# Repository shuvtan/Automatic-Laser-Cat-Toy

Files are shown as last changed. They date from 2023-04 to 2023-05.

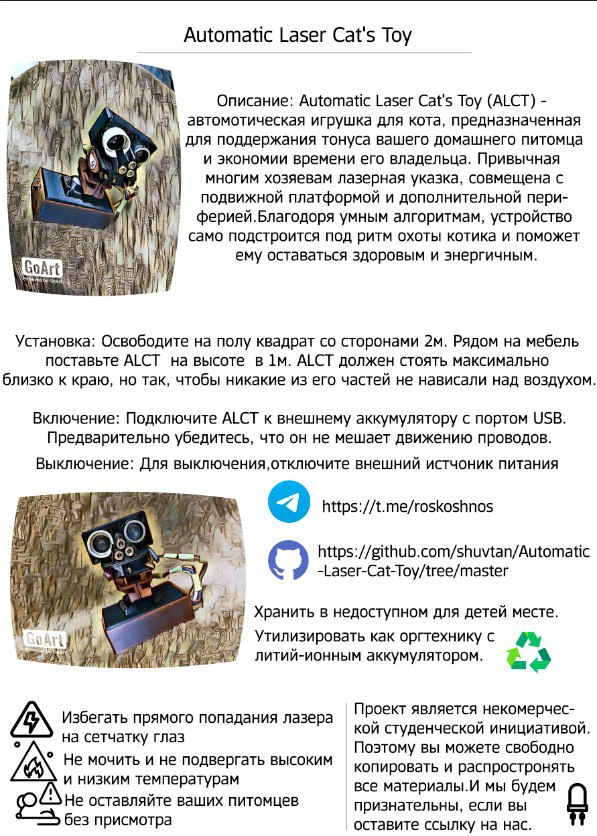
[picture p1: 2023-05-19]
ALCT_instruction.jpg

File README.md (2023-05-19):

# Automatic-Laser-Cat-Toy

**НПО Роскошнос представляет...**

*Автоматическая лазер-игрушка для котиков*

# Структура
Идея продукта: [ALCT idea](https://github.com/shuvtan/Automatic-Laser-Cat-Toy/blob/master/ALCT%20idea.pdf)

Документация продукта и протокол испытаний: [ALCT_production](https://github.com/shuvtan/Automatic-Laser-Cat-Toy/blob/master/ALCT%20%D0%94%D0%BE%D0%BA%D1%83%D0%BC%D0%B5%D0%BD%D1%82%D0%B0%D1%86%D0%B8%D1%8F%20%D0%B8%20%D0%BF%D1%8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)

Инструкция пользователя: [ALCT_instruction](https://github.com/shuvtan/Automatic-Laser-Cat-Toy/blob/master/ALCT_instruction.jpg)

Схема систем: [ALCT Cхема систем](https://github.com/shuvtan/Automatic-Laser-Cat-Toy/blob/master/ALCT%20%D0%A1%D1%85%D0%B5%D0%BC%D0%B0%20%D1%81%D0%B8%D1%81%D1%82%D0%B5%D0%BC.jpg)

Прошивка устройства и тест-код: [Код](https://github.com/shuvtan/Automatic-Laser-Cat-Toy/tree/master/%D0%9A%D0%BE%D0%B4) -

Модели для 3D печати: [Модели 3D печать](https://github.com/shuvtan/Automatic-Laser-Cat-Toy/tree/master/%D0%9C%D0%BE%D0%B4%D0%B5%D0%BB%D0%B8%203D%20%D0%BF%D0%B5%D1%87%D0%B0%D1%82%D1%8C)

# Соцсети
За процессом работы следите в нашем Telegram канале: [РОСКОШНОС](https://t.me/roskoshnos)

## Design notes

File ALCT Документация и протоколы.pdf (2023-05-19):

ФЕДЕРАЛЬНОЕ ГОСУДАРСТВЕННОЕ АВТОНОМНОЕ ОБРАЗОВАТЕЛЬНОЕ УЧРЕЖДЕНИЕ ВЫСШЕГО ОБРАЗОВАНИЯ МОСКОВСКИЙ ФИЗИКО-ТЕХНИЧЕСКИЙ ИНСТИТУТ (НАЦИОНАЛЬНЫЙ ИССЛЕДОВАТЕЛЬСКИЙ УНИВЕРСИТЕТ) ФАКУЛЬТЕТ ОБЩЕЙ И ПРИКЛАДНОЙ ФИЗИКИ

Документация инженерного продукта Автоматическая лазерная игрушка для котов Automatic Laser Cat’s Toy

Мясникова Алина, Стельмух Никита, Сметанина Елена, Шувайникова Татьяна

Долгопрудный, 2023 г.

## 1 Описание

Автоматическая лазерная игрушка для кота - далее устройство.

Данное устройство представляет собой совокупность систем модулей электроники, управление которыми производится с помощью микроконтроллера Arduino Nano.

Применение: При подключении устройства в сеть, фиксируется игровая площадка, после чего загораются три лазера, способные привлечь внимание кота. В режиме реального времени с помощью дальнометра устройство способно определить поймал кот лазер или нет. В зависимости от этого с помощью сервоприводов лазеры направляются в другую точку, изменяя направление цели кота.
Таким образом устройство поможет отвлечь кота, пока хозяин занят своими делами.

## 2 Комплектация

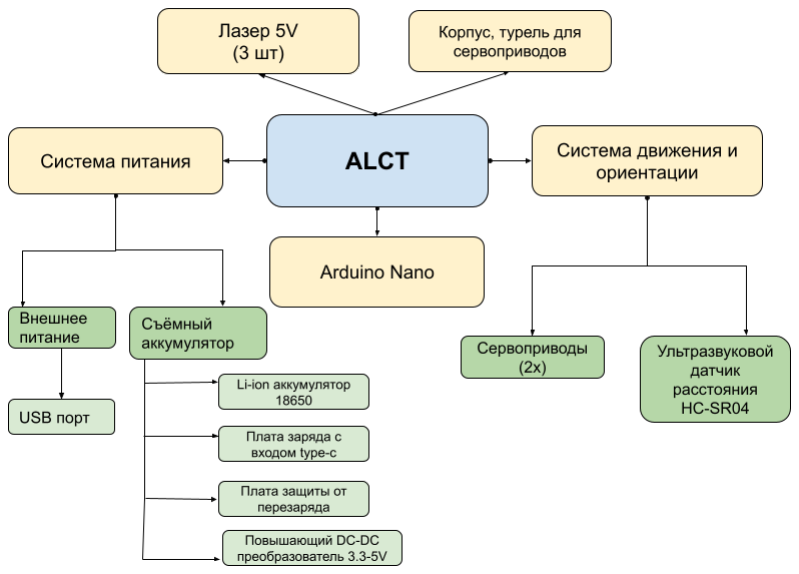
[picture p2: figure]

Рис. 1: Схема деления систем устройства

Устройство состоит из 5 основных систем:

1. Бортовая машина
- Микроконтроллер Arduino Nano
- Тактовая кнопка для перезагрузки платы
2. Полезная нагрузка
- Лазер 5V (3 шт.)

3. Корпус
- Основной корпус для электронники
- Крышка корпуса
- Турель для сервоприводов SG90/MG90
- Корпус для датчика дальности
- Держатель лазеров
4. Система питания

4.1 Внешнее питание

- USB порт

4.2 Съёмный аккумулятор

- Li-ion аккумулятор 18650
- Плата заряда с входом type-c
- Плата защиты от перезаряда (может идти вместе с аккумулятором)
- Повышающий DC-DC преобразователь 3.3-5V
- Микропереключатель
- Светодиоды для определения состояния
5. Система движения и ориентации
- Сервопривод SG90
- Сервопривод MG90
- Ультразвуковой датчик дальности HC-SR04

После составления сметы, была посчитана примерная стоимость продукта - 2480 рублей.
Данная стоимость была расчитана на основании стоимости электронных компонент в интернет магазине chip.dip. (https://www.chipdip.ru/)

Стоит отметить, что 3D печать элементов корпуса обошлась бесплатно. Приносим благодарность Физтех.Фабрике (https://miptfab.ru/) !

Компоненты | шт | Цена, руб
Плата Arduino Nano | 1 | 300
Сервомотор SG90 | 1 | 150
Сервопривод MG90 | 1 | 200
Ультразвуковой датчик HC–SR04 | 1 | 450
Лазер 5V | 3 | 100
Резистор 133 Ω | 1 | 100
Аккумулятор Li-ion 18650 с защитой | 1 | 930
Плата с гнездом USB Type-C | 1 | 150
Повышающий DC-DC преобразователь до 5 В | 1 | 60
Тактовая кнопка | 1 | 15
Микропереключатель | 1 | 25
Корпус | 1 | 0
Крышка для корпуса | 1 | 0
Турель для сервоприводов SG90/MG90 | 1 | 0
Итого: | | 2480

Таблица 1: Стоимость компонент

## 3 Технические характеристики

1. Микроконтроллер Arduino Nano
В качестве бортовой машины используется микроконтроллер Arduino Nano. Такой выбор был сделан из-за компактности при достаточной эффективности. Данная машина работает на чипе ATmega328P.

Технические характеристики:

- Напряжение питания 5В;
- Количество цифровых пинов – 14, из них 6 могут использоваться в качестве выходов ШИМ;
- 8 аналоговых входов;
- Максимальный ток цифрового выхода 40 мА;
- Флэш- память 16 Кб
- ОЗУ 1 Кб
- Частота 16 МГц;
- Размеры 19 х 42 мм;
- Вес 7 г.
2. Дальнометр HC-SR04
Принцип работы: Ультразвуковой датчик расстояния работает по принципу эхолокации — посылает пучок ультразвука и получает его отражение с некоторой задержкой, с помощью которой рассчитывается расстояние до объекта.

На передней части модуля расположено два ультразвуковых датчика, первый с надписью T (Transmiter) является передатчиком ультразвуковых волн, а второй с надписью R (Receiver) служит приёмником отражённых волн.

Подключение: Датчик оснащён четырьмя выводами. Два стандартных вывода для питания и земли, вывод Trig подключается к цифровому пину Arduino в качестве сигнала входа, вывод Echo подключается к цифровому выводу Arduino в качестве сигнала вывода.

Этапы получения данных с помощью датчика:

- На выход Trig подаётся импульс длительностью 10 микросекунд;
- Трансмиттер отправляет 8 импульсов с частотой 40 кГц;
- Когда импульсы отразятся от препятствия и будут приняты ресивером, то на выходе Echo образуется входной сигнал;
- Ширина импульса преобразуется в расстояние с помощью формулы.Чтобы получить расстояние в сантиметрах, нам необходимо разделить ширину импульса на 58.

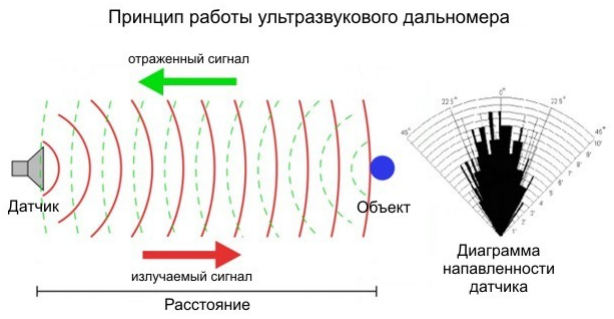
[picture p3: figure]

Рис. 2: Принцип работы дальнометра

Технические характеристики:

- Напряжение питания: 5В
- Диапазон расстояний: 2–400 см
- Точность: 0.3 см
- Эффективный угол обзора: 15°
- Рабочий угол наблюдения: 30°
- Рабочая температура: от 0°С до +60°С
- Габариты: 45мм×20мм×15мм

3. Сервоприводы SG90 и MG90

Сервопровид типа SG90 расположен в нижней части конструкции устройства. Данный датчик отвечает за поворот устройства в горизонтальной плоскости (XoY).

Характеристики SG90:

- Скорость вращения (4.8В без нагрузки): 0.14 сек/60 градусов
- Максимальный угол поворота: 180 градусов
- Рабочая температура: от -30°С до +60°С
- Рабочее напряжение: 3.5 - 8.4В
- Габариты: 22.6 x 21.8 x 11.4 мм
- Масса: 13 г.

Сервомотор типа MG90 расположен в верхней части устройства. Данный датчик отвечает за поворот устройства в вертикальной плоскости (XoZ).

Характеристики MG90:

- Скорость вращения (4.8В без нагрузки): 0.1 сек/60 градусов
- Максимальный угол поворота: 160 градусов
- Рабочая температура: от -30°С до +60°С
- Рабочее напряжение: от 3V до 7.2V (Вольт)
- Габариты: 22mm x 11.5mm x 22.5mm
- Масса: 9 г.
4. Лазерный излучатель 5В

Лазерный излучатель с радиатором охлаждения - это простой и недорогой вариант точечного света.

Характеристики:

- Напряжение питания: 5 Вольт DC
- Цвет излучения: 650 нм (красный)
- Вид излучения: точка
- Рабочий ток: < 40 мА
- Мощность излучения: < 5 мВт
- Размеры: диаметр 6 мм, длина 10.5 мм
- Рабочая температура: от -36℃ до 65℃

## 4 Алгоритмизация

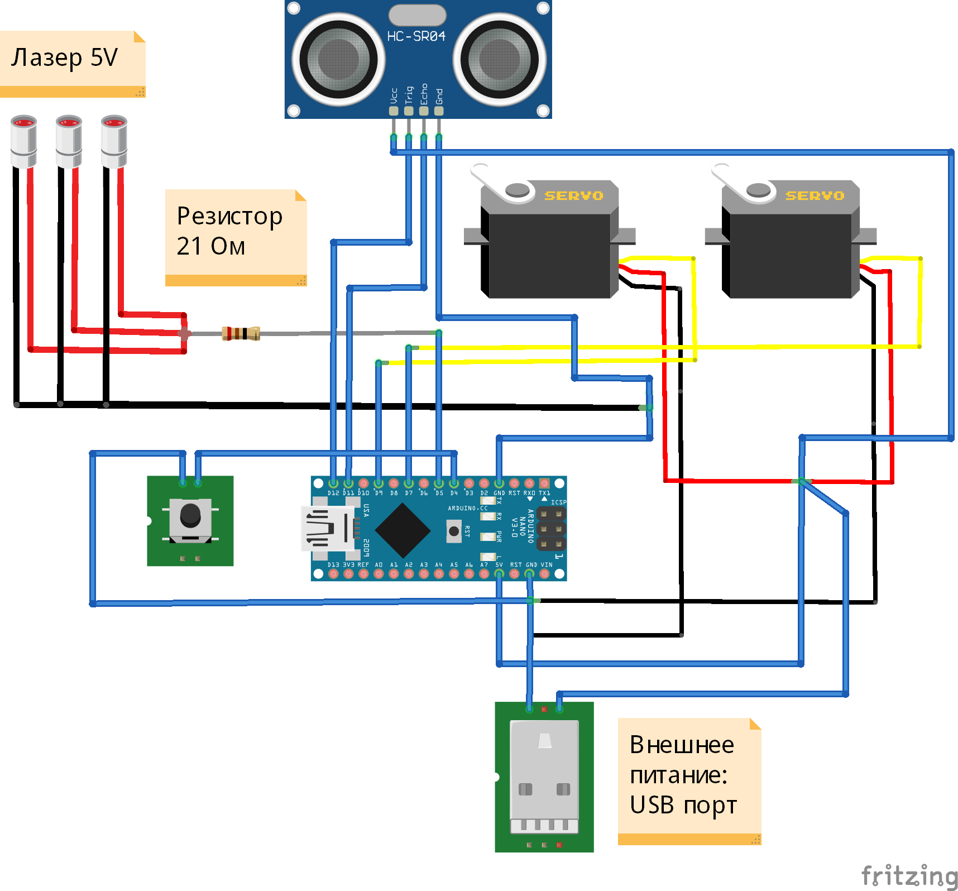
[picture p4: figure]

Рис. 3: Схема соединения модулей электронники

Компонента | PIN
Сервомотор SG90 | 7
Сервопривод MG90 | 9
Датчик дальности - TRIG | 12
Датчик дальности - ECHO | 11
Лазеры 5V | 5
Тактовая кнопка | 4

Таблица 2: Распиновка электронники

В прошивке устройства использованы базовые программы работы движения сервоприводов на рандомный угол и фиксации изменения расстояния до объекта с помощью дальнометра.

Логика кода: Если расстояние, зафиксированное датчиком изменилось более, чем на 10 см, то кот поймал лазер -> через секунду лазер поменяет положение с помощью движения сервоприводов. Если в течение минуты изменение расстояния не было зафиксировано (кот по какой-либо причине не поймал лазер), то вновь срабатывает алгоритм поворота - лазер перебегает в другое место. Код с подробными комментариями смотрите в репозитории гитхаб в папке Код (https://github.com/shuvtan/Automatic-Laser-Cat-Toy/tree/master/%D0%9A%D0%BE%D0%B4)

## 5 Корпус

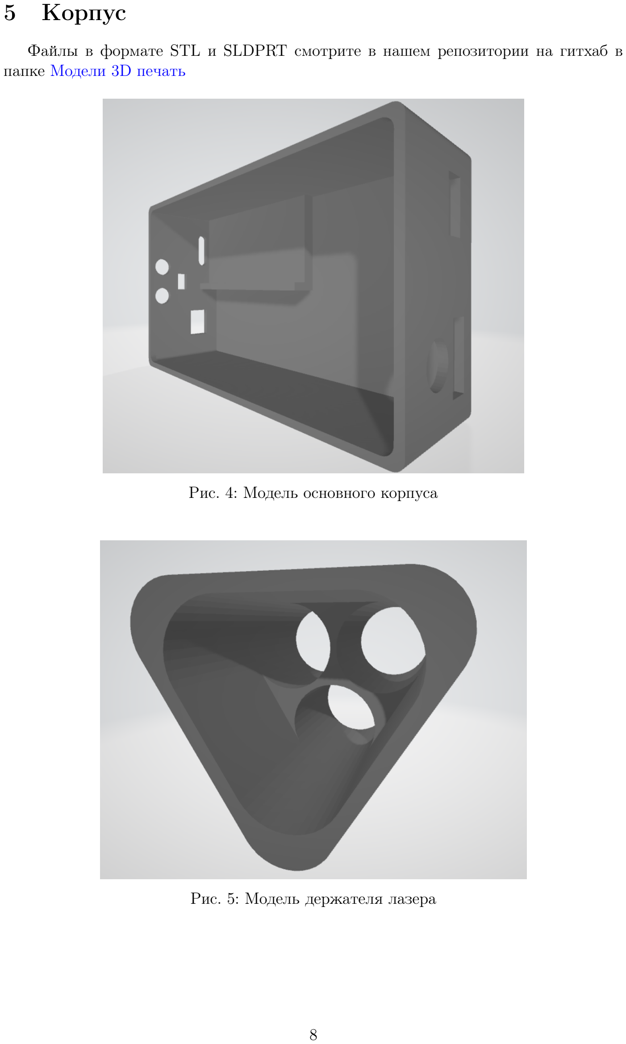
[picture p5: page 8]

Файлы в формате STL и SLDPRT смотрите в нашем репозитории на гитхаб в папке Модели 3D печать (https://github.com/shuvtan/Automatic-Laser-Cat-Toy/tree/master/%D0%9C%D0%BE%D0%B4%D0%B5%D0%BB%D0%B8%203D%20%D0%BF%D0%B5%D1%87%D0%B0%D1%82%D1%8C)

Рис. 4: Модель основного корпуса

Рис. 5: Модель держателя лазера

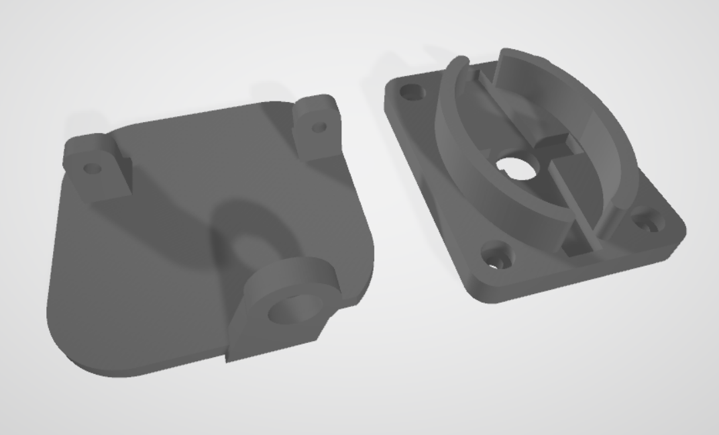
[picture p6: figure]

Рис. 6: Модель нижней и верхней частей турели для сервоприводов

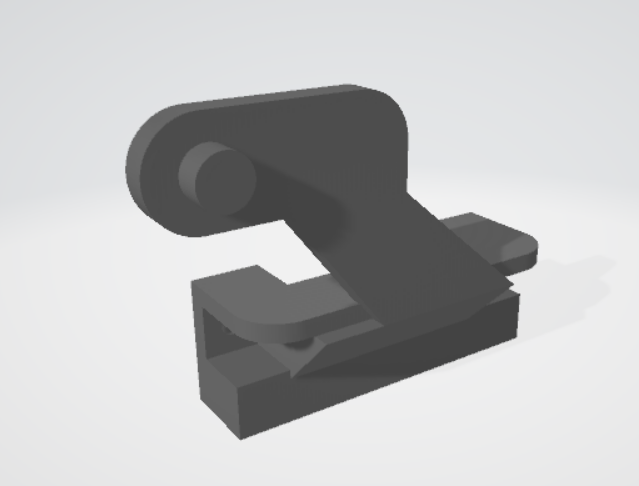
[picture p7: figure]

Рис. 7: Модель боковой части турели для сервоприводов

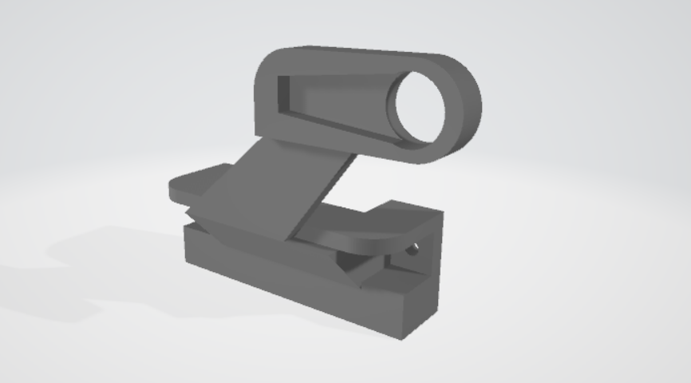
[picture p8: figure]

Рис. 8: Модель боковой части турели для сервоприводов

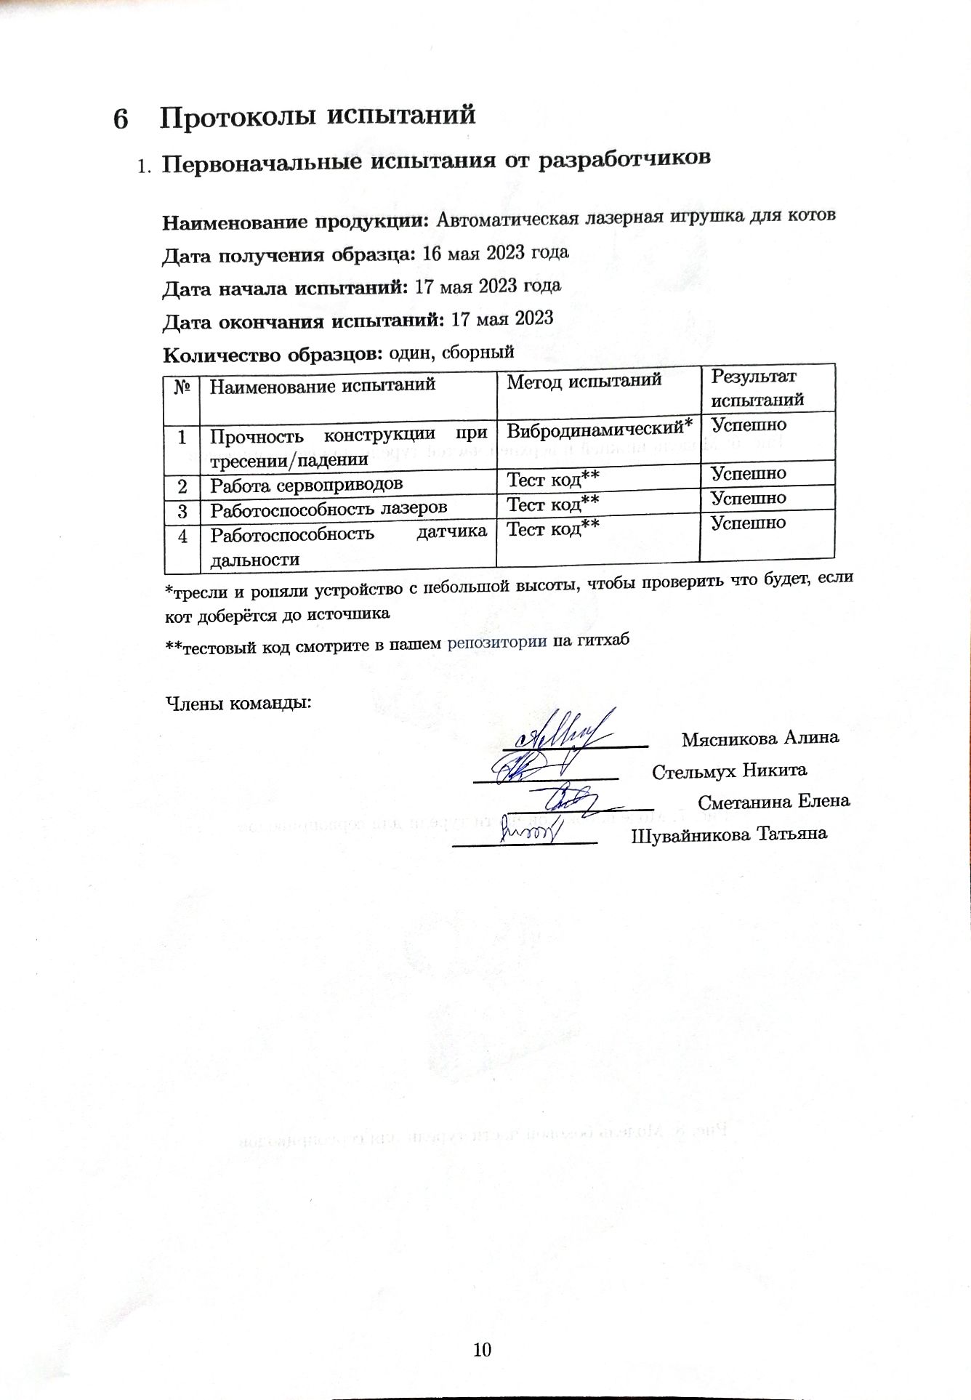
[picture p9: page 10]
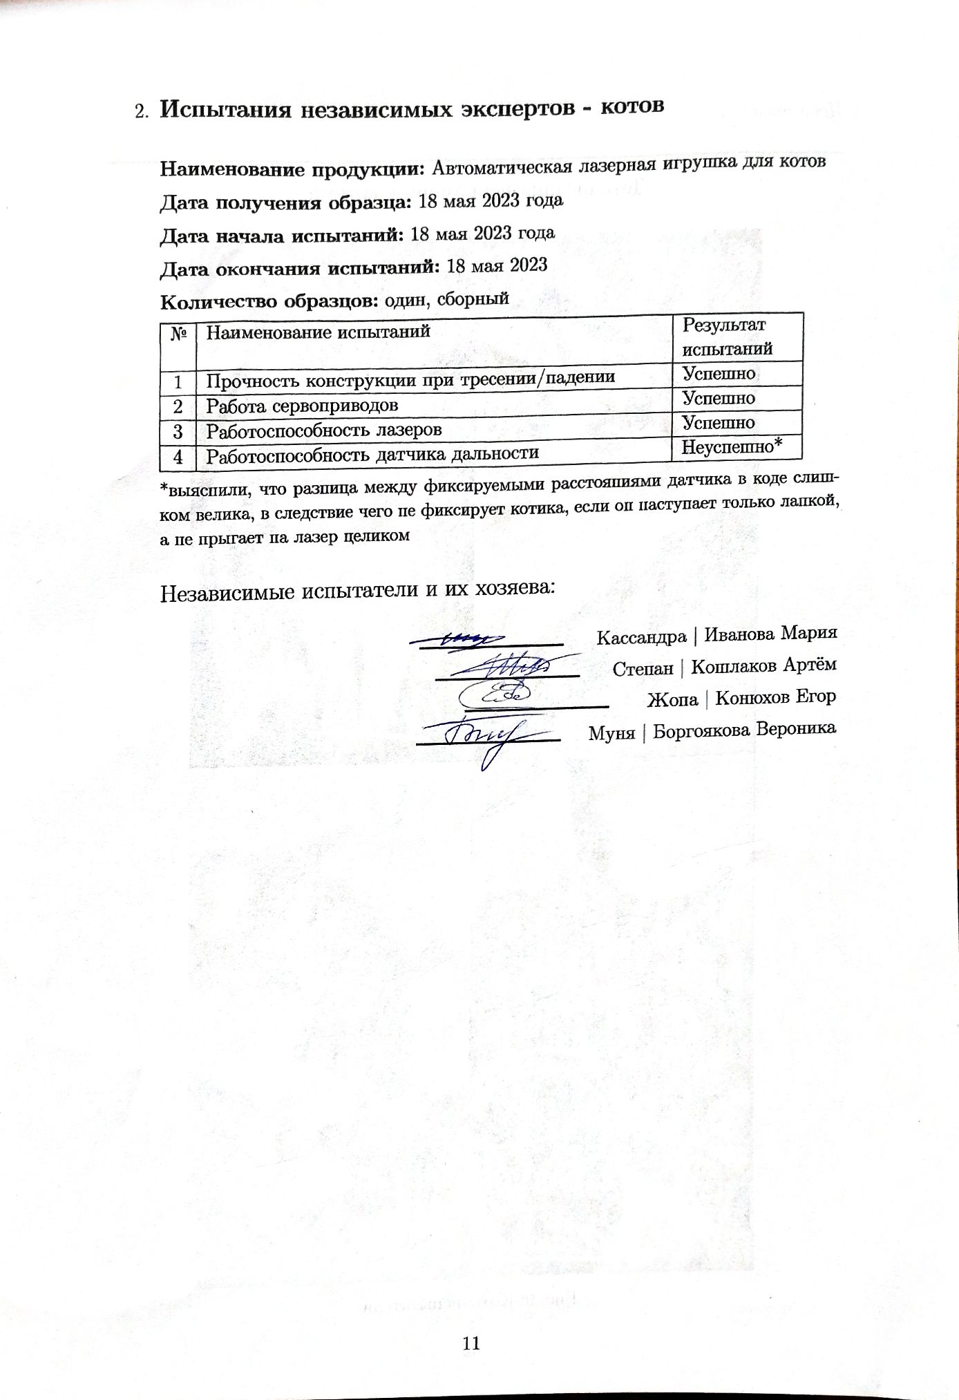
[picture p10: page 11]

Приложение 1

Детализация испытаний с котами

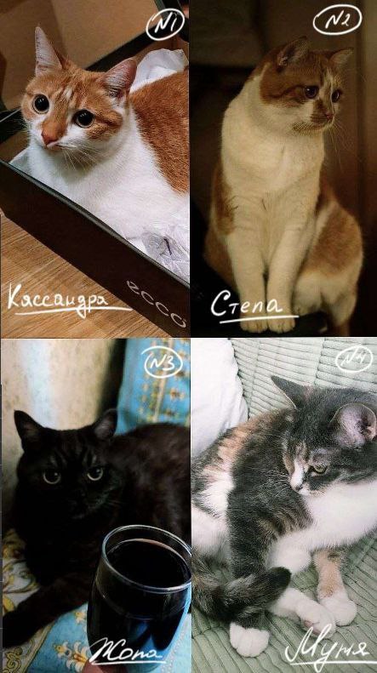
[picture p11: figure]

Рис. 9: Коты-испытатели

1. Кассандра

Кассандра несильно заинтересовалась лазерной игрушкой. Мы думаем, что это может быть связано с ярким освещением комнаты, в которой проводились испытания. Чтобы не подвергать котиков опасности попадания лазера в глаза, лазер настроен не на полную мощность, из-за чего в слишком хорошо освещённой комнате кот может не заметить игрушку.
Кассандра оказалась умной кошечкой. Услышав звук, она заинтересовалась непосредственно источником, её привлекло именно вращение самого устройства, а не лазерный луч, излучённый им. Вскоре кошка потеряла интерес к устройству вообще.

В ходе первого эксперимента мы сталкнулись с двумя проблемами:

- Звук, издаваемый сервоприводами при повороте привлёк кошку больше, чем сам лазер.
- Лазер плохо видно в освещённой комнате
2. Степан

Степан оказался более заинтересованным в происходящем. Вначале игрушку расположили слишком низко - на стуле. Поэтому Степа заинтересовался источником, тщательно его изучил, даже потрогал. Так мы убедились в том, что если кот доберётся до игрушки, то вряд ли будет атаковать, скорее заинтересуется или даже немного испугается при очередном движении сервоприводов. После этого лазерную игрушку переместили повыше - на стол. К сожалению, Степан тоже больше был заинтересован в звуках, чем в лазерном луче. К тому же он порой отвлекался на какие-либо другие посторонние звуки, например работающая в комнате мультиварка.
Тем неменее спустя время, аккуратный Степан осмелился потрогать луч, располагающийся у него прямо под лапками. После чего немного походил за лазером, но быстро устал и ушёл спать на своё место.

В момент, когда Степа тронул лапой лазерную точку мы увидили главную на данный момент проблему - неисправность режима датчика дальности! После того, как кот тронул точку, она не сдвинулась, потому что изменение расстояния было меньше 10 см (лапка кота поменьше).

В ходе второго эксперимента мы сталкнулись с двумя новыми проблемами:

- Постаронние звуки отвлекали кота от лазерной игрушки
- Слишком осторожный кот будет ловить лазер лапкой, которая даст результат изменения расстояния меньше 10 см, предполагаемого в прошивке устройства.

3. Жопа

Жопа оказался достаточно пугливым котом, поэтому испытания проводили только сами хозяева, поделившись с нами видеоматериалами.
В отличие от первых двух экспериментов данное испытание проводилось в более тёмном помещении. К сожалению это не повлияло на повышение интереса кота к игрушке.

Жопа внимательно наблюдал за лазерной точкой, но не атаковал её. Тут мы увидели ещё одну недоработку. В данном эксперименте лазер часто попадал на самого кота сзади например, так, что кот не понимал где находится лазер, не видел его, из-за чего мог потерять интерес.

Снова была подтверждена проблема срабатывания алгоритма по изменению расстояния датчика дальности, т.к. Жопа если ловил лазер, то только лапой, не слишком активно, в следствие чего расстояние менялось менее чем на 10 см.

В ходе третьего эксперимента мы сталкнулись с новыми проблемой:

- Режим работы лазера не исключает случая, когда лазер попадает на тело кота таким образом, что кот теряет лазер, не понимая, что происходит
4. Муня

Самым активным и заинтересованным испытателем определённо стала Муня. У этой кошечки хорошо развиты охотничьи инстинкты, ей понравилось охотиться за лазером. Она активно прыгала и нападала на лазерную точку, иногда отходя в засаду, чтобы выждать подходящего момента.

Так мы проверили срабатывание движения сервоприводов по таймеру, если кот не ловит лазерную точку более минуты. Снова убедились в недееспособности алгоритма измерения изменения расстояния, при случаях, если Муня ловила лазер только лапкой. Но к счастью это не помешало данной кошечке насладиться игрой, потому что она активно атаковала лазерный луч, в следствие чего измеренная разница расстояний была определенно больше 10 см.

Стоит отметить новую проблему для активных котиков: после выключения лазера кошечка продолжнала искать его по всей комнате. Кроме того охотница слишком разыгралась и перевозбудилась, потому что играла около 12 минут.

В ходе последнего эксперимента мы сталкнулись с новой проблемой:

- Активные котики могут слишком сильно разыграться, если использовать игрушку долго - более 10 минут.

## 7 Итоги испытаний и дальнейшая разработка

Основные проблемы и анализ их решения:

- В ходе испытаний стало понятно, что разницу изменения расстояния, в момент, когда кот поймает лазер нужно делать менее 10 см, как мы поставили изначально. Тем не менее меньше 5 см делать ёё тоже не стоит, т.к. из-за неточности измерения значений датчика будут ловиться бесконечные ложные срабатывания, такие, что точка ни на мг не застынет на месте.
Было принято решение поменять данный параметр на 8 см.
- Кроме того в ходе испытаний было проверено, что остальные проблемы возникшие при проектировке устройства были решены качественно, так, что системы работают исправно.
- Трения между сервоприводами и колебаний устройства за счёт смещения центра масс не наблюдалось. Значит подкладки справляются достаточно хорошо, проблема, возникшая во время проектировки решена качественно.
- Чтобы сузить радиус углового обзора датчика дальности и сфокусировать датчик дальности на измерение расстояния непосредственно до объекта точечно, куда падает лазер, был спроектирован небольшой цилиндр, сужающий угол обзора датчика.
Вначале испытаний мы заподозрили, что алгоритм изменения координат не срабатывает именно из-за перекрытия цилиндром сигнала датчика, но сняв данную деталь мы убедились, что это не так. Несрабатывания алгоритма происходят именно из-за просчётов в измерении разницы расстояний, а не из-за перекрытия сигнала.
Наличие цилиндра показало, что с ним реакция датчика на посторонние движения вне точки лазера всё же уменьшеается, т.е. данное инженерное решение было результативным и верным.

Идеи дальнейшего развития продукта:

- Добавление новых алгоритмов, расчитанные на котиков разной активности
- Питание от съёмного аккумулятора 3.3V
- Выбор режима пользователем (например яркости лазера, режимом игры по активности кота и т.п.)

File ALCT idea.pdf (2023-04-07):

# Automatic Laser Cat’s Toy

## “НПО Роскошнос” представляет…

Московск Фко-технческ нсттут , 2023

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

## Научно-технческе адач:

◇ Собрать модель автоматческо лаерно укак, меняюще свое направлене в авсмост от поведеня кота, на основе Arduino Nano
◇ Раработать несколько алгортмов-паттернов для котов рано актвност
◇ Испытать прбор, проаналровать поведене котовтестровщков

## Схема сстем:

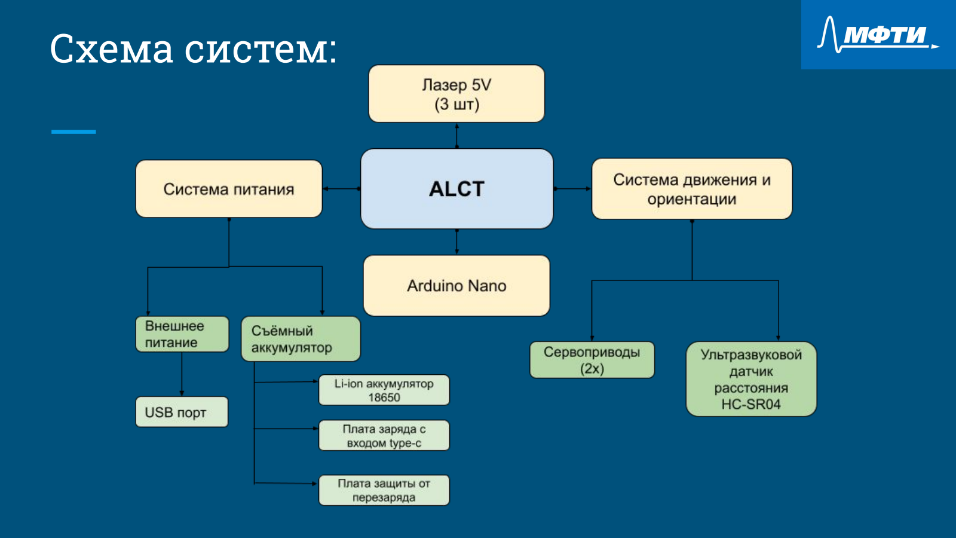
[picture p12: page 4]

## Состав команды:

- Стельмух Нкта - руководтель НПО, ненер-электронщк
- Мяснкова Ална - конструктор, smm-менедер
- Сметанна Елена - конструктор, сследователь
- Шуванкова Татьяна - программст алгортмов, сследователь

МФТИ, Факультет аэрокосмческх технолог, группа: Б03-102

## План-графк работы:

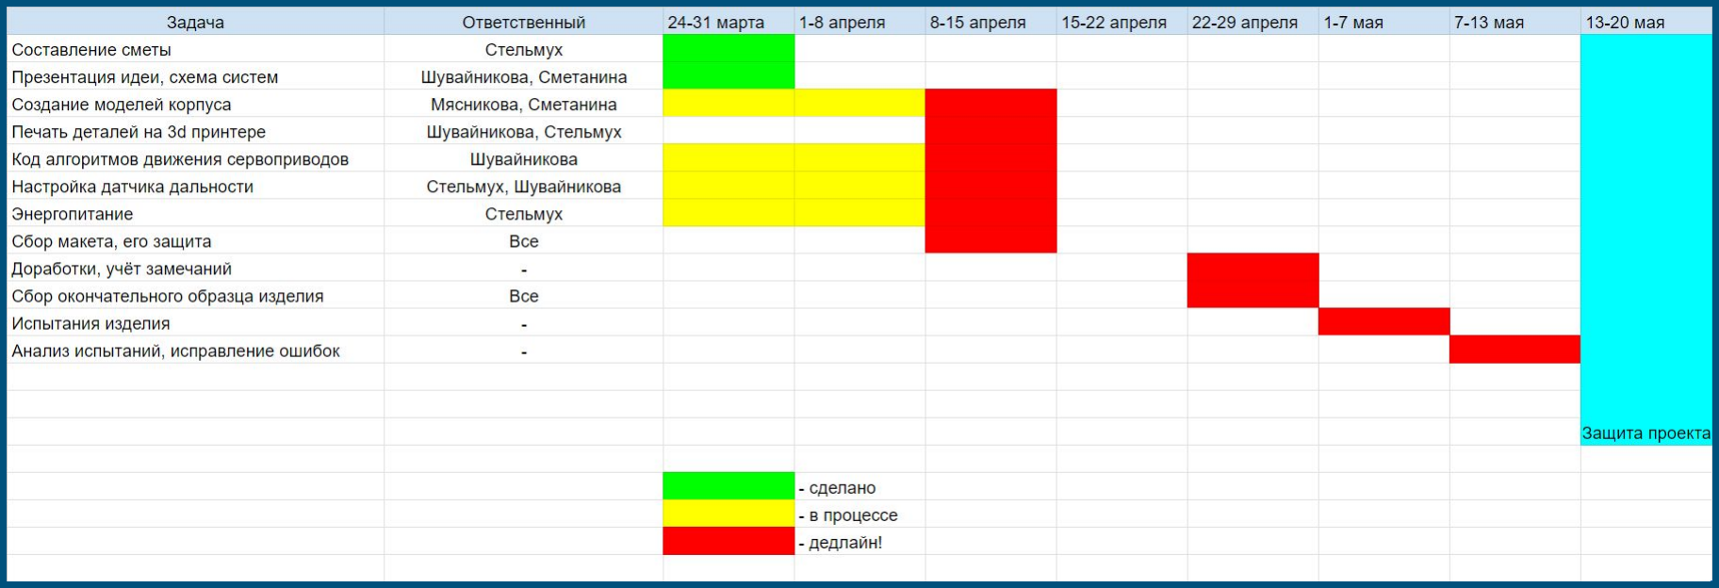
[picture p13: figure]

## Следте а нашм прогрессом…

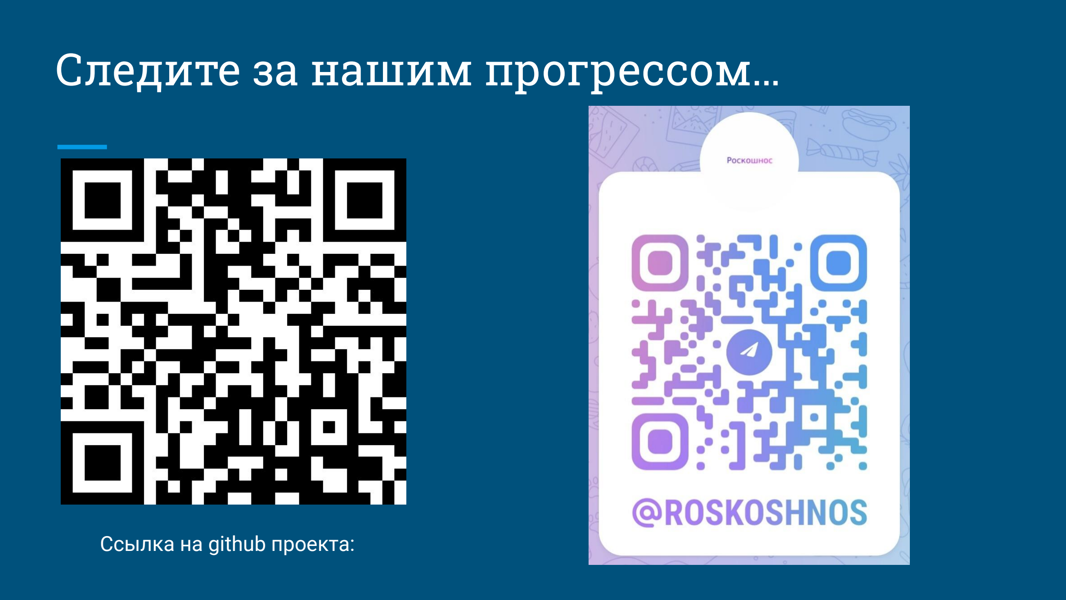
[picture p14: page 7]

Ссылка на github проекта:
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

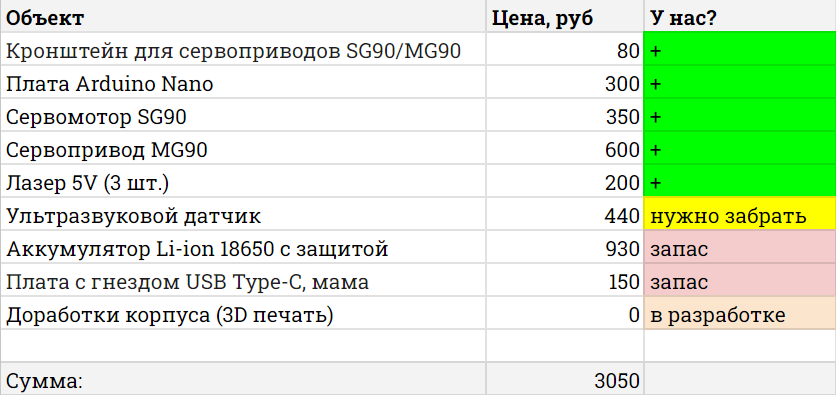
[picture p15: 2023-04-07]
ALCT Смета.png

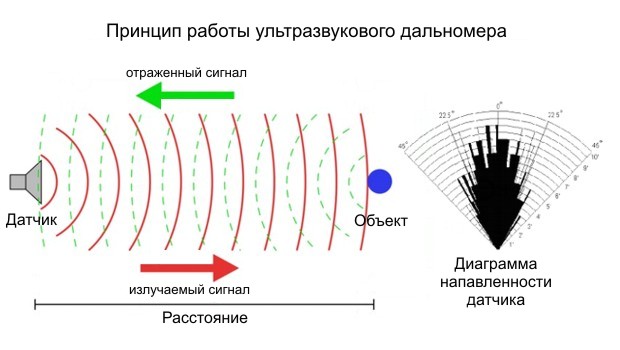
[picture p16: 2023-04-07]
Принцип работы ультразвукового датчика.jpg

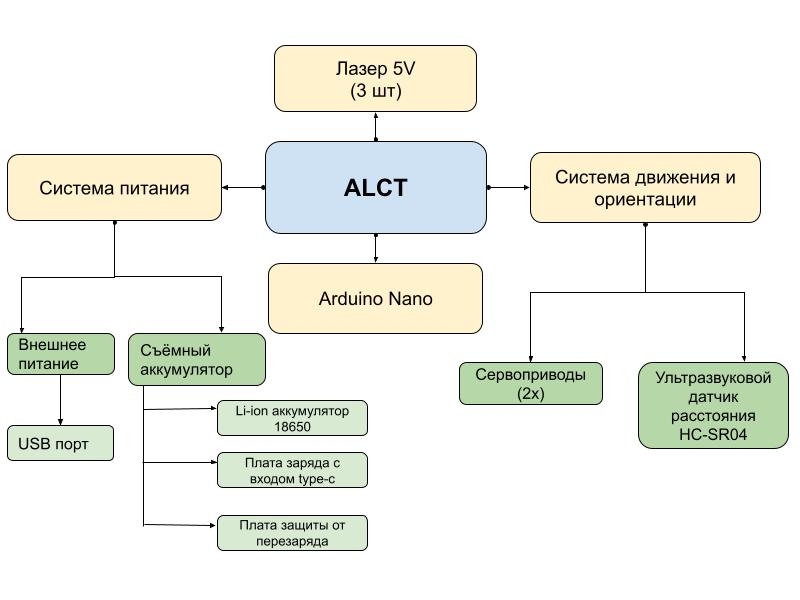
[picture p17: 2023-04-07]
ALCT Схема систем.jpg

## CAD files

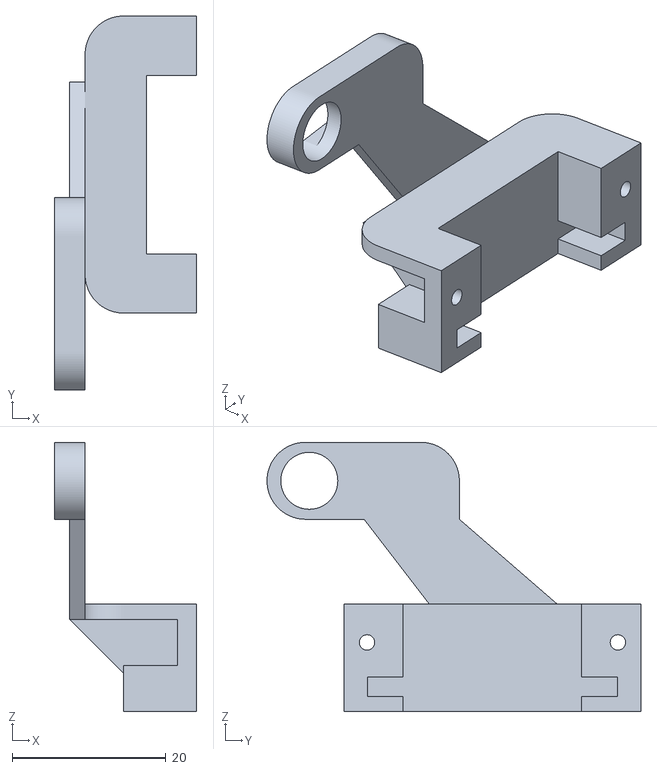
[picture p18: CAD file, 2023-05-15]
Модели 3D печать/HolderR-servo.stl
18.5 x 48.6 x 35.0

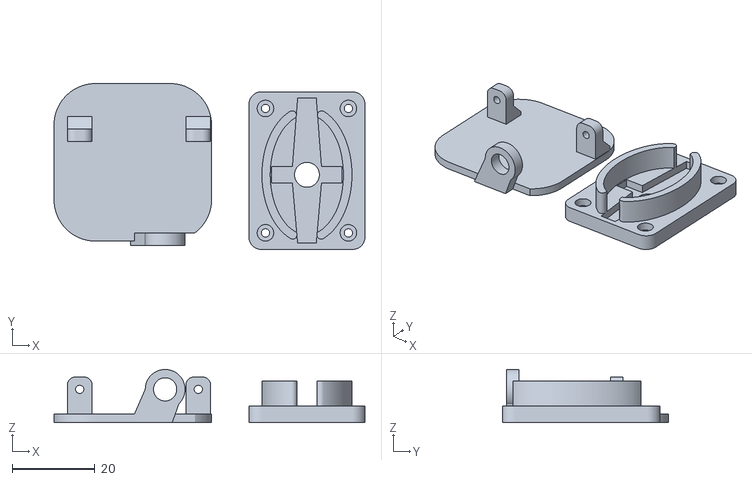
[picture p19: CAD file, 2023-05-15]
Модели 3D печать/base-servo.stl
75.0 x 40.0 x 12.8

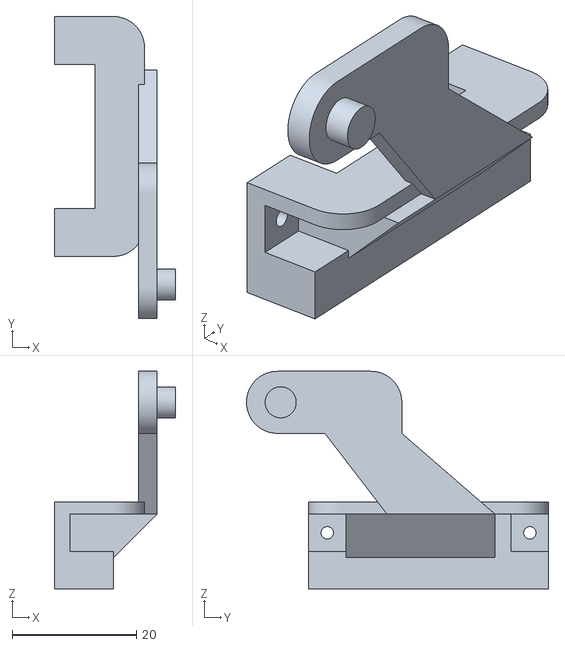
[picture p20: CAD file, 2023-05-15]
Модели 3D печать/HolderL-servo.stl
19.5 x 48.6 x 35.0

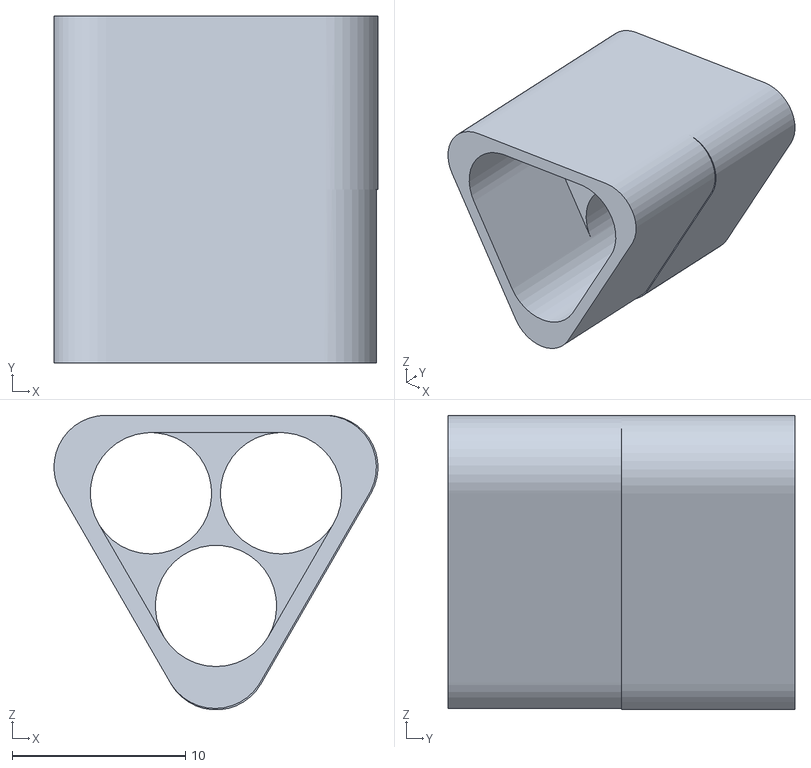
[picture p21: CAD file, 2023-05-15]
Модели 3D печать/laser-20-ALCT.STL
18.7 x 20.0 x 17.0

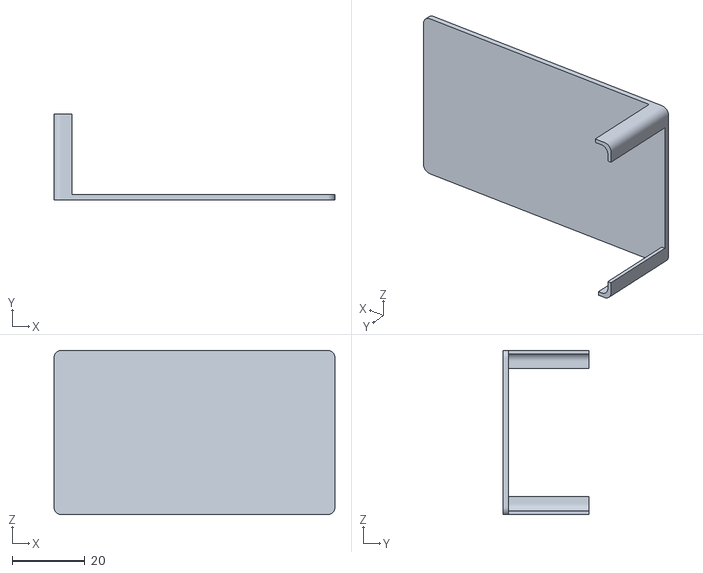
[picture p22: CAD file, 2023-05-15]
Модели 3D печать/krishka-20-ALCT.STL
77.0 x 23.5 x 45.0

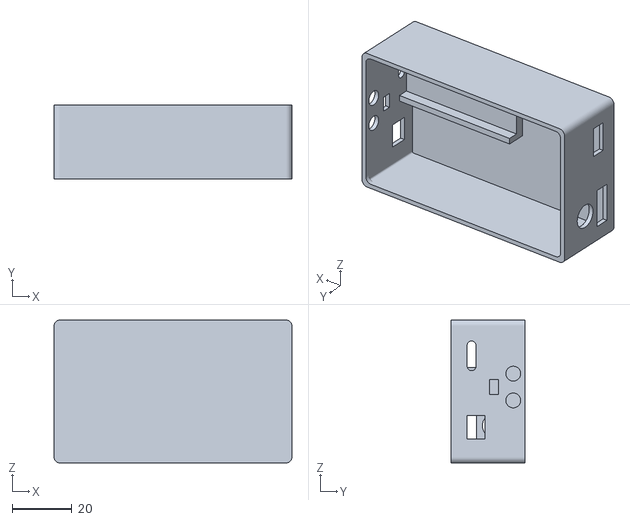
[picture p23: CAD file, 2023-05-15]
Модели 3D печать/box-20-ALCT.STL
80.0 x 25.0 x 48.0

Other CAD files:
Модели 3D печать/laser-ALCT.SLDPRT
Модели 3D печать/krishka-ALCT.SLDPRT
Модели 3D печать/box-ALCT.SLDPRT

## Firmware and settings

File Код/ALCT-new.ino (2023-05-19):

/*
Laser Tower for the CAT - LA FABRIQUE DIY
Pseudo-randomly moves a servo tower (on X and Y axis) and lights up a laser.
x_servo is attached to pin 7 and moves in the X plan
y_servo is attached to pin 9 and moves in the Y plan
Laser is on pin 5

HOW IT WORKS :
The program randomly choose a new position for the laser inside a square you can define below.
It checks the new position is different from the old one of at least "minimal_movement".
It moves the tower to the new position and stays still for a time between min_freeze and max_freeze
(this aims to reproduce the behaviour of an insect landing somewhere for a bit and then flying off,
that's the variable you need to increase if your cat is fat).
Ans starts the process over and over again.

Created 30 Sep 2016 by Lucas Berbesson
*/

//Подключаем нужные библиотеки
#include <Servo.h>
#include <NewPing.h>

 //Подключаем датчик дальности
#define PIN_TRIG 12 //пускает сигнал
#define PIN_ECHO 11 //принимает сигнал

#define MAX_DISTANCE 200 // Константа для определения максимального расстояния, которое мы будем считать корректным.

// Создаем объект, методами которого будем затем пользоваться для получения расстояния.
// В качестве параметров передаем номера пинов, к которым подключены выходы ECHO и TRIG датчика

NewPing sonar(PIN_TRIG, PIN_ECHO, MAX_DISTANCE);

/*Можем менять начальные параметры, задания игровой площади */

// X - угол в горизонтальной плоскости  [min_x, max_x] - сервопривод пин 7
// Y - угол в вертикальной плоскости [min_y, max_y] - сервопривод пин 9

float min_x = 40;
float max_x = 140;
float min_y = 70;
float max_y = 120;
int min_freeze = 800;
int max_freeze = 4000;
float minimal_movement = 5;
int testmode = 0; // uncomment for testing
/* YOU SHOULD NOT HAVE TO MODIFY THE CODE BELOW THIS LINE */

// Находим центр игровой площади
int random_delay;
float x_position = min_x + (max_x - min_x)/2;
float y_position = min_y + (max_y - min_y)/2;
float x_old_position = x_position;
float y_old_position = y_position;
float x_new_position;
float y_new_position;
float x_speed;
float y_speed;
int movement_time;

// Подключаем сервоприводы
Servo x_servo;
Servo y_servo;
int pos = 0;

void setup() {
Serial.begin(9600);
y_servo.attach(9); // Сервопривод вертикальной плоскости Y - пин 9
x_servo.attach(7); // Сервопривод вертикальной плоскости X - пин 7
pinMode (5, OUTPUT);
digitalWrite (5, HIGH); // Включаем лазер

//Центровка - начальное состояние прибора
y_servo.write(y_position);
x_servo.write(x_position);

if (testmode > 0) {
for(int i=10; i<(10); i++) {
x_servo.write(i);
Serial.print("X=");
Serial.println(i);
delay(100);
}
x_servo.write(x_position);
for(int i=10; i<(10); i++) {
y_servo.write(i);
Serial.print("Y=");
Serial.println(i);
delay(100);
}
}
}

void loop() {

unsigned int distance2=0;
unsigned int time1=0;
unsigned int time2=0;
unsigned int time3=0;
for (int i = 0;; i += 1) {
  time1 = millis();
  delay(50); //Стартовая задержка для корректной работы

  // Получаем значение от датчика расстояния и сохраняем его в переменную
  unsigned int distance1 = sonar.ping_cm();

 //Если котик поймал лазер, т.е. расстояние до объекта изменилось -> меняем положение
  if (abs(distance1-distance2)>=8) {
   delay(30);
   basic();
   time2 = millis();
  }
 
 if (abs(time1-time2)>60000){
 delay(30);
 basic();
 time2 = millis();
 }
}
}

void basic(){
   //Выбираем параметры для рандомного поворота
    movement_time = random(20,50);
    x_new_position = random(min_x+minimal_movement, max_x-minimal_movement);
    y_new_position = random(min_y+minimal_movement, max_y-minimal_movement);

    if( (y_new_position > y_old_position) && (abs(y_new_position - y_old_position) < 5 )) {
    y_new_position = y_new_position + minimal_movement;
    } else if ( (y_new_position < y_old_position) && (abs(y_new_position - y_old_position) < 5 )) {
    y_new_position = y_new_position - minimal_movement;
    }

    if( (x_new_position > x_old_position) && (abs(x_new_position - x_old_position) < 5 )) {
    x_new_position = x_new_position + minimal_movement;
    } else if ( (x_new_position < x_old_position) && (abs(x_new_position - x_old_position) < 5 )) {
    x_new_position = x_new_position - minimal_movement;
    }

    x_speed = (x_new_position - x_old_position)/movement_time;
    y_speed = (y_new_position - y_old_position)/movement_time;
    
    //Пересчитываем координаты при повороте
    for (pos = 0; pos < movement_time; pos += 1) {
    x_position = x_position + x_speed;
    y_position = y_position + y_speed;
    x_servo.write(x_position);
    y_servo.write(y_position);
    delay(50);
    }
    x_old_position = x_new_position;
    y_old_position = y_new_position;
    //Запоминаем новое расстояние до объекта, пока котик не поймал лазер
    unsigned int distance2 = sonar.ping_cm();
}

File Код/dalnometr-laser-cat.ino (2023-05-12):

#include <NewPing.h>

#define PIN_TRIG 12
#define PIN_ECHO 11

#define MAX_DISTANCE 200 // Константа для определения максимального расстояния, которое мы будем считать корректным.

// Создаем объект, методами которого будем затем пользоваться для получения расстояния.
// В качестве параметров передаем номера пинов, к которым подключены выходы ECHO и TRIG датчика

NewPing sonar(PIN_TRIG, PIN_ECHO, MAX_DISTANCE);

void setup() {
  // Инициализируем взаимодействие по последовательному порту на скорости 9600
  Serial.begin(9600);
  pinMode (5, OUTPUT); // подключаем к пину светодиод
}

void loop() {
  unsigned int distance2=0;
  for (int i = 0;; i += 1) {
  // Стартовая задержка, необходимая для корректной работы.
  delay(50);

  // Получаем значение от датчика расстояния и сохраняем его в переменную
  unsigned int distance1 = sonar.ping_cm();
  if (distance1!=distance2) {digitalWrite(5,1);}
  distance2 = sonar.ping_cm();

  // Печатаем расстояние в мониторе порта
  Serial.print(distance1);
  Serial.println("см");
  }


}

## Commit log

2023-03-30 Презентация идеи продукта
2023-03-30 Схема систем
2023-04-07 Идея продукта
2023-04-07 Схема систем ALCT
2023-04-07 Смета реализации продукта
2023-04-07 Схема соединения элементов электронники
2023-04-07 Распиновка в программе Fritzing
    [pin.fzz]
2023-04-07 Принцип работы ультразвукового датчика
2023-05-12 Базовый код датчик+сервоприводы
2023-05-12 Код для проверки работы датчика дальности
2023-05-12 Код для проверки работы лазера и сервоприводов
2023-05-15 Основа корпус файл SLDPRT
    [box-ALCT.SLDPRT]
2023-05-15 Основа корпус файл STL
    [box-20-ALCT.STL]
2023-05-15 Крышка корпуса файл SLDPRT
    [krishka-ALCT.SLDPRT]
2023-05-15 Крышка корпуса файл STL
    [krishka-20-ALCT.STL]
2023-05-15 Держатель лазеров файл SLDPRT
    [laser-ALCT.SLDPRT]
2023-05-15 Держатель лазеров файл STL
    [laser-20-ALCT.STL]
2023-05-15 Турель для сервоприводов файлы STL
    [HolderL-servo.stl, HolderR-servo.stl, base-servo.stl]
2023-05-15 Код для проверки датчика дальности
2023-05-16 Основной режим: сервоприводы+дальнометр+лазер
2023-05-19 Документация продукта
2023-05-19 Обновлённые код после испытаний
2023-05-19 Обновление распиновки
    [pin.fzz]
2023-05-19 Инструкция пользователя
2023-05-19 Техническая документация и протоколы испытаний
